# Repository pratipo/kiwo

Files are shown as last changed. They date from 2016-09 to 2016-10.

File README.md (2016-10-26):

# kiwo
post digital knitting, hybrid fabrication, digital crafts, social looming
 
> “El acto de tejer se convierte en una metáfora de la vida diaria, y también en una herramienta para construir espacio, construir grupos y comunidades, actividades e ideales que de otra forma permanecerían escondidos, olvidados o perdidos” 
> In The Loop, Knitting now. Jessica Hemmings (2010)

###Overview
Kiwo is an augmented rag loom, an artifact for hybrid fabric manufacture. It's a digital, interactive loom that can manage complex patterns in a user-friendly way. 

An augmented loom is not an elektroknit machine (a fully automated robot into which you feed a pattern and it takes over both the act of producing and the product), nor a traditional loom that gives no feedback to the user. Kiwo is a prototype designed to preserve all the properties of the craft production activity (inherent to the product and the social, physical and emotional activity itself) while speeding up the ability to learn new stitches and transform the number of patterns created or shared into tangible fabrics.

Using a series of simple sensors and actuators Kiwo is able to read the user's work and guide how fabrics are made out of different stitches. Multi-coloured patterns can be made too, by using several strands of colour to produce pictures, motifs and symbols. These complex patterns can be computer generated and easily transferred to the artefact (previously or) after they have been (self)made or distributed.  

A mobile app allows users to transfer these patterns into Kiwo, while enjoying outdoor and social life.

###Tech

A MEAN2 stack ecosystem plus an electronic device thaqt receives knitting-pattern data through BLE
 * Mongo schema wip
 * Ionic2 port wip
 * Nodejs wip
 
 * Pcb and bom wip (ws2812 + ble + 328)
 * Loom body and needle wip
 * Stitch detection wip
  
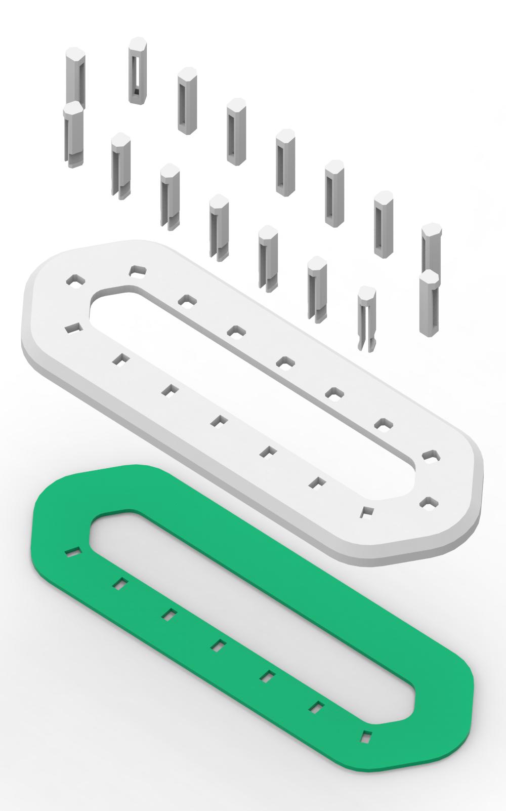
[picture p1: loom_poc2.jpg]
second poc. with needle A vs needle B

second poc. needle A vs needle B

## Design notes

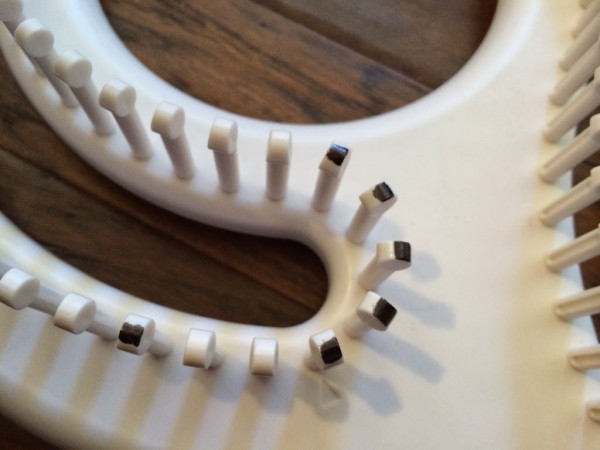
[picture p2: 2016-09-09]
proposal/marker patterns on loom.jpg

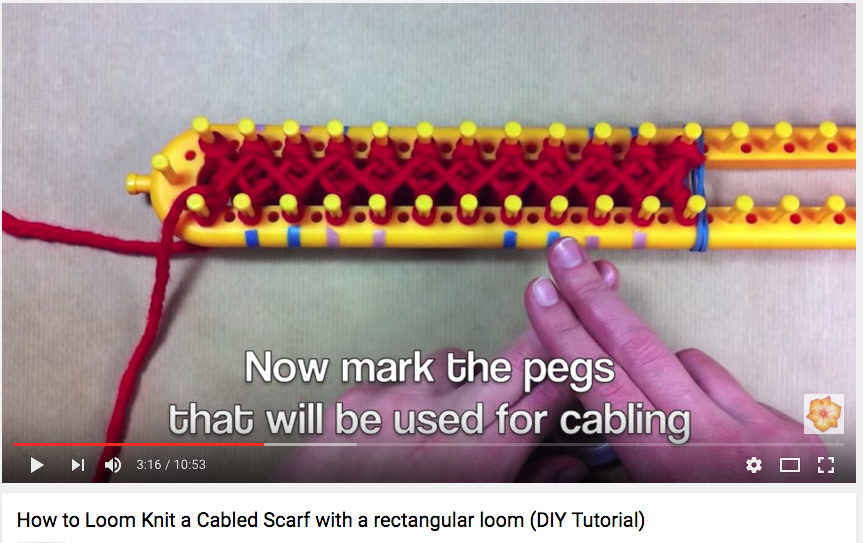
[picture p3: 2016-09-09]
proposal/color tape patterns on loom.png

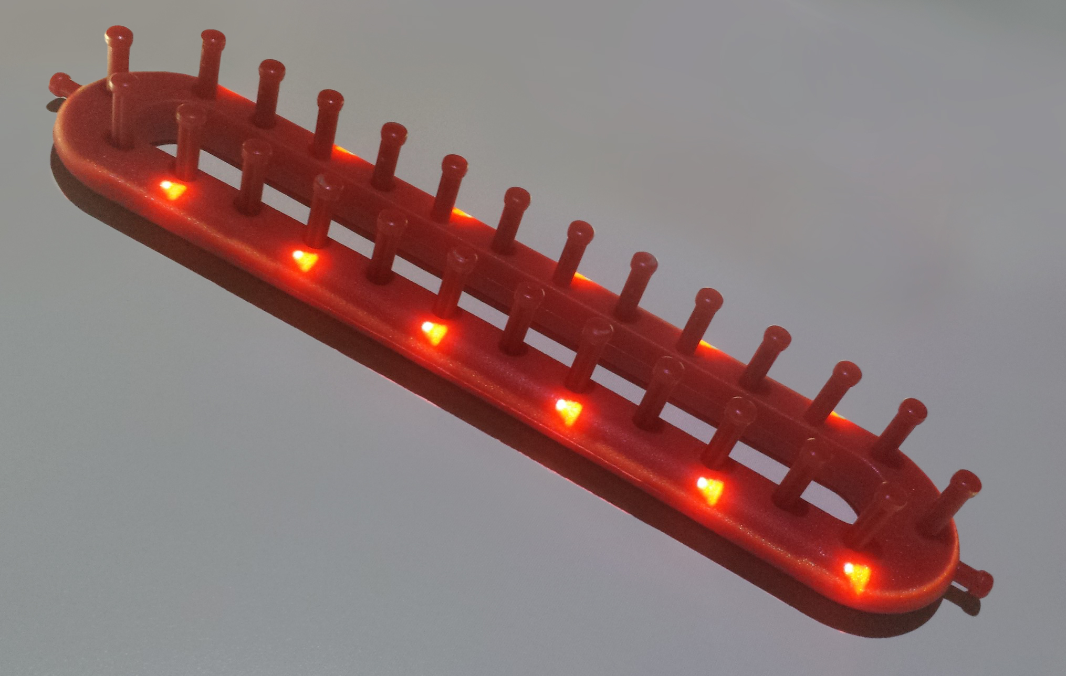
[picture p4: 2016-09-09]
proposal/kiwo_mockup.jpg

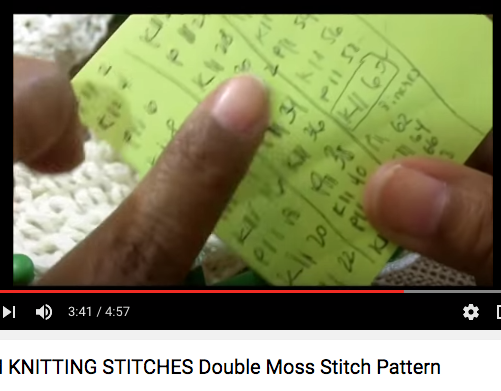
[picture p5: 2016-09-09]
proposal/paper patterns.png

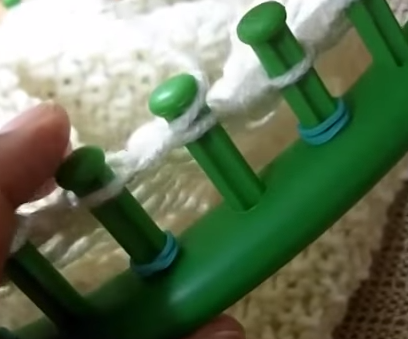
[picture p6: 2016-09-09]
proposal/rubberband patterns on loom.png

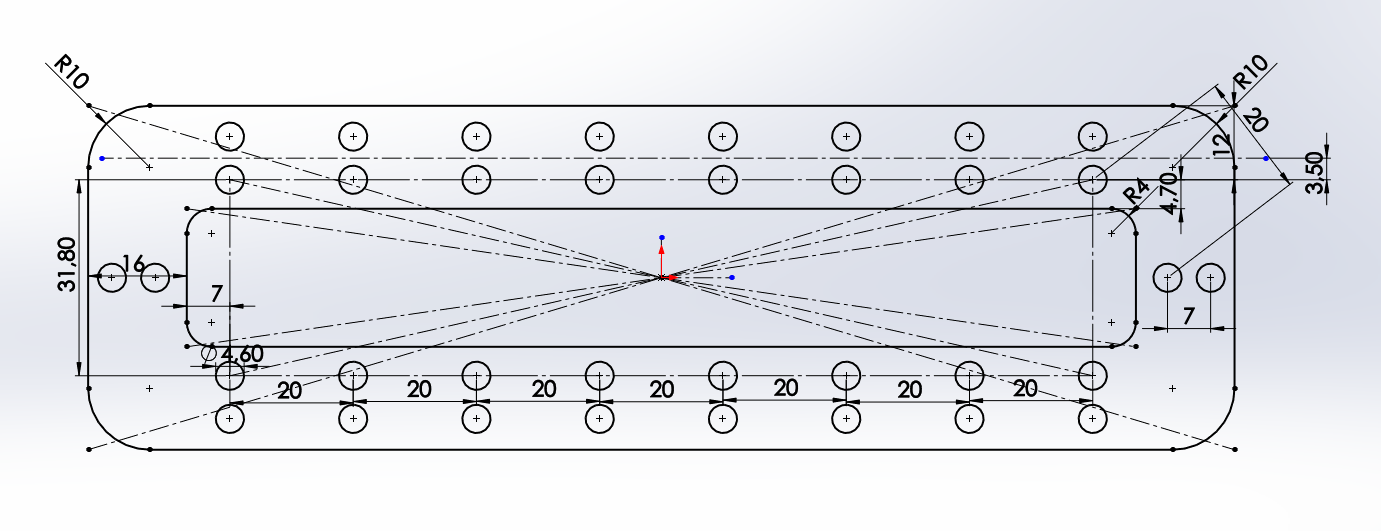
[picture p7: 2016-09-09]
kiwo_loom_poc1/loom_poc1.png

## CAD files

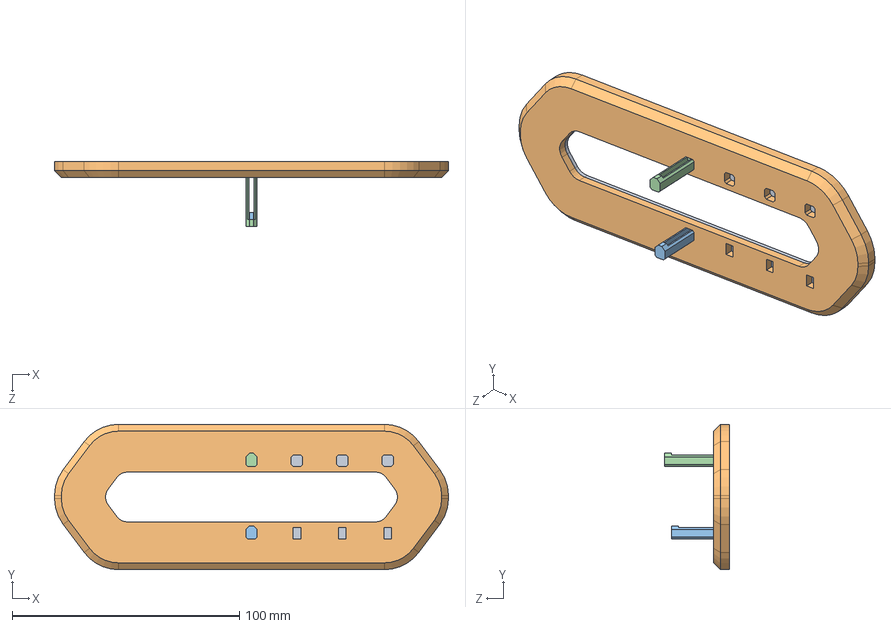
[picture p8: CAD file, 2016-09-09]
kiwo_loom_poc2/kiwo_poc2.SLDASM
173.5 x 64.0 x 28.6 mm
pcb^kiwo_poc2
case^kiwo_poc2
peg^kiwo_poc2
peg2^kiwo_poc2

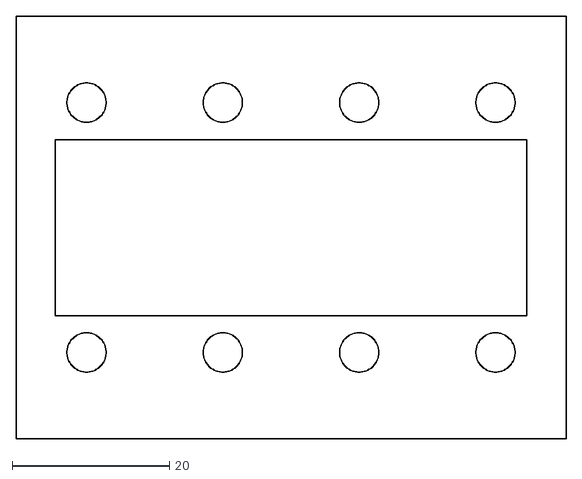
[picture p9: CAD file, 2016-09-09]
kicad/kiwo_poc1/kiwo_poc1.dxf
70.0 x 53.8

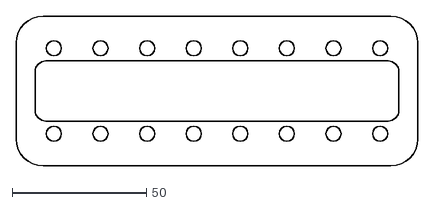
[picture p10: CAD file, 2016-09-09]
kicad/kiwo_poc2/kiwo_poc2_.dxf
149.5 x 55.8

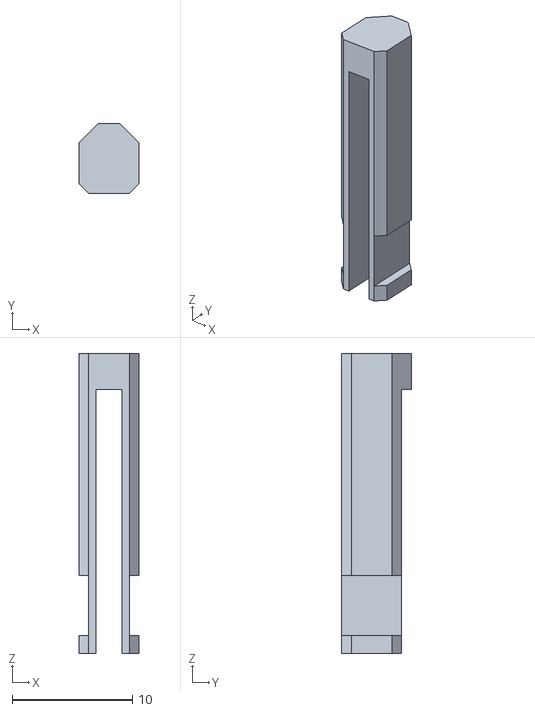
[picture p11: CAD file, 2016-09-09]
kiwo_loom_poc2/kiwo_peg0.STL
5.00 x 5.80 x 25.0

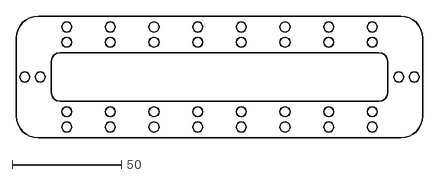
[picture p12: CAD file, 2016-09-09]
kiwo_poc0/kiwo.DXF
186.0 x 55.8

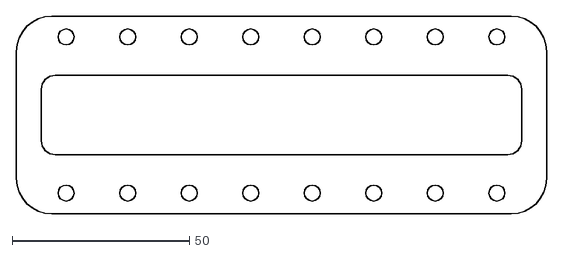
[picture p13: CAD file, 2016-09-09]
kicad/kiwo_poc2/kiwo_poc2_analogtest.dxf
149.5 x 55.8

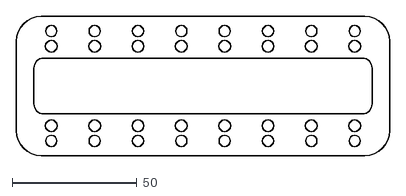
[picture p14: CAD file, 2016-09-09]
kicad/kiwo_poc2/kiwo_poc2_wood.dxf
149.5 x 55.8

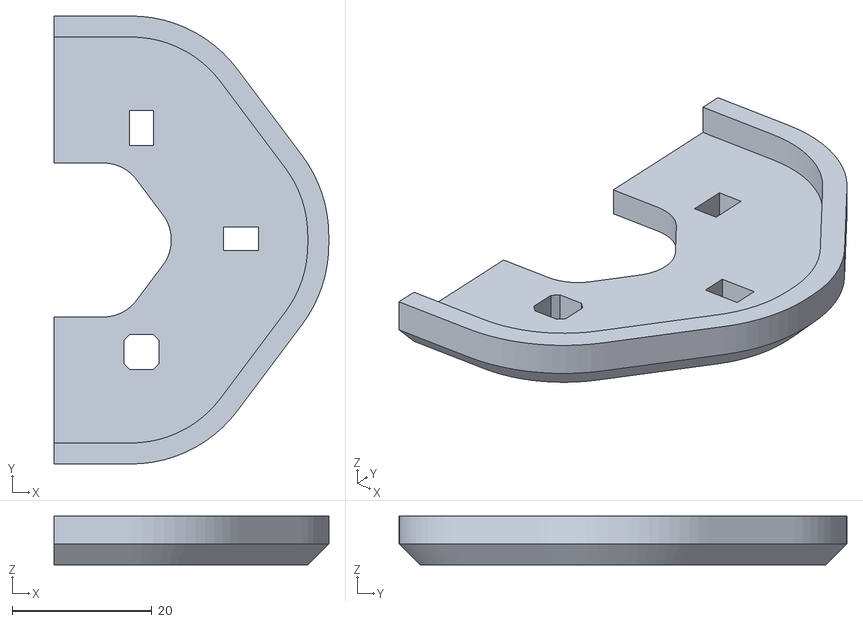
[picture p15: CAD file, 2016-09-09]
kiwo_loom_poc2/kiwo_case.STL
39.2 x 64.0 x 7.00

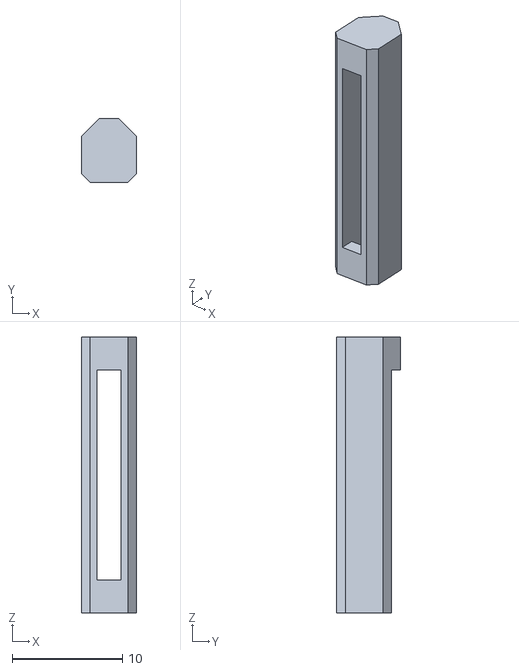
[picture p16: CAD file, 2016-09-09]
kiwo_loom_poc2/kiwo_peg1.STL
5.00 x 5.80 x 25.0

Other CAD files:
kiwo_loom_poc1/kiwo_poc1_cut_shape.SLDPRT
kicad/kiwo_poc1/kiwo_poc1_.DXF
kiwo_loom_poc2/kiwo_poc2.sldprt

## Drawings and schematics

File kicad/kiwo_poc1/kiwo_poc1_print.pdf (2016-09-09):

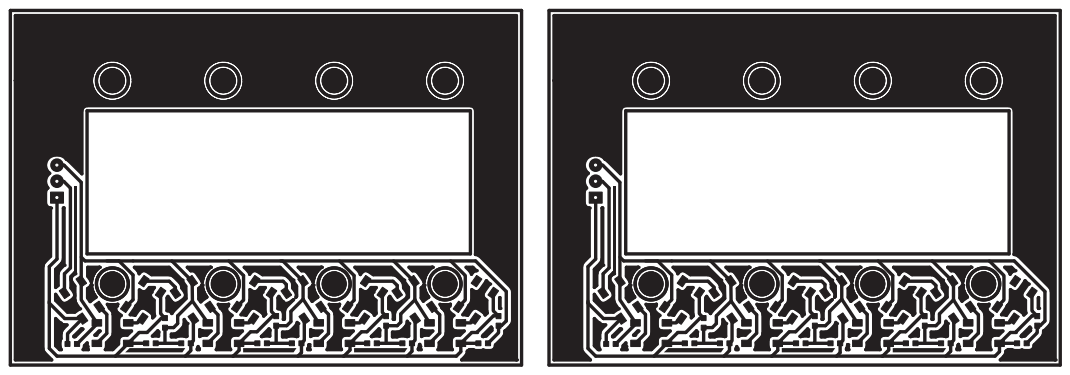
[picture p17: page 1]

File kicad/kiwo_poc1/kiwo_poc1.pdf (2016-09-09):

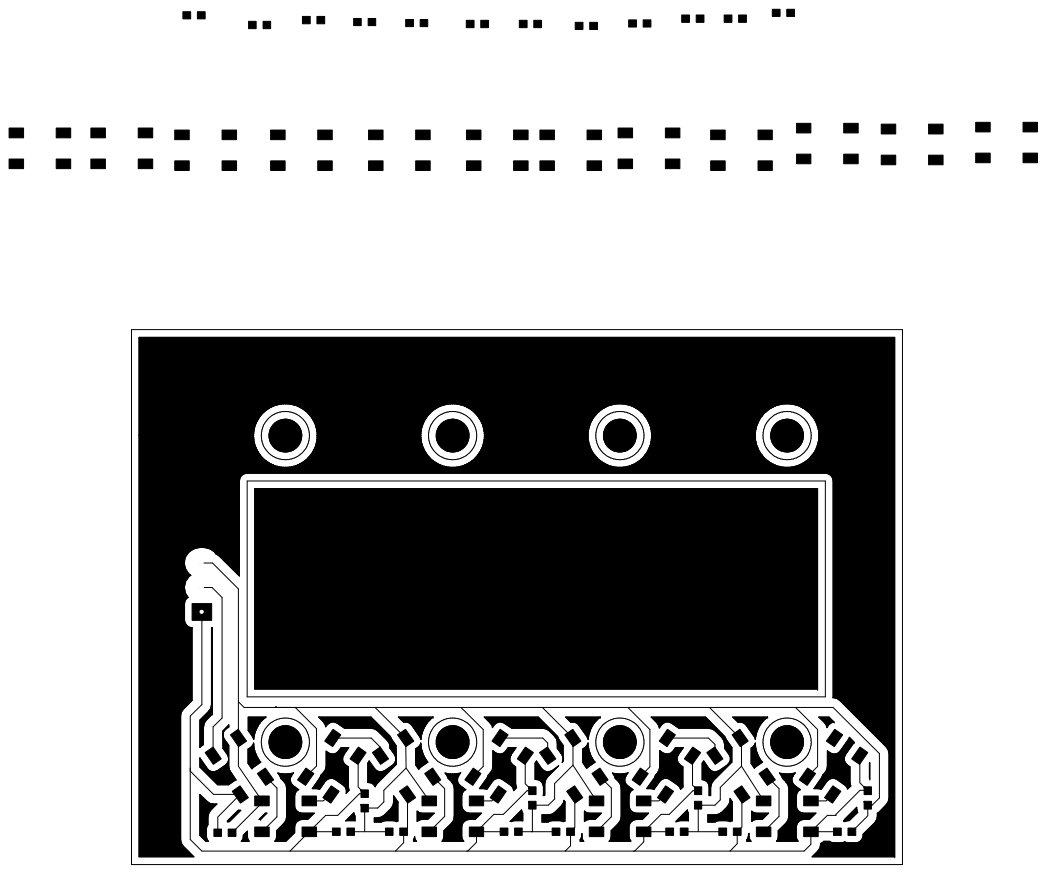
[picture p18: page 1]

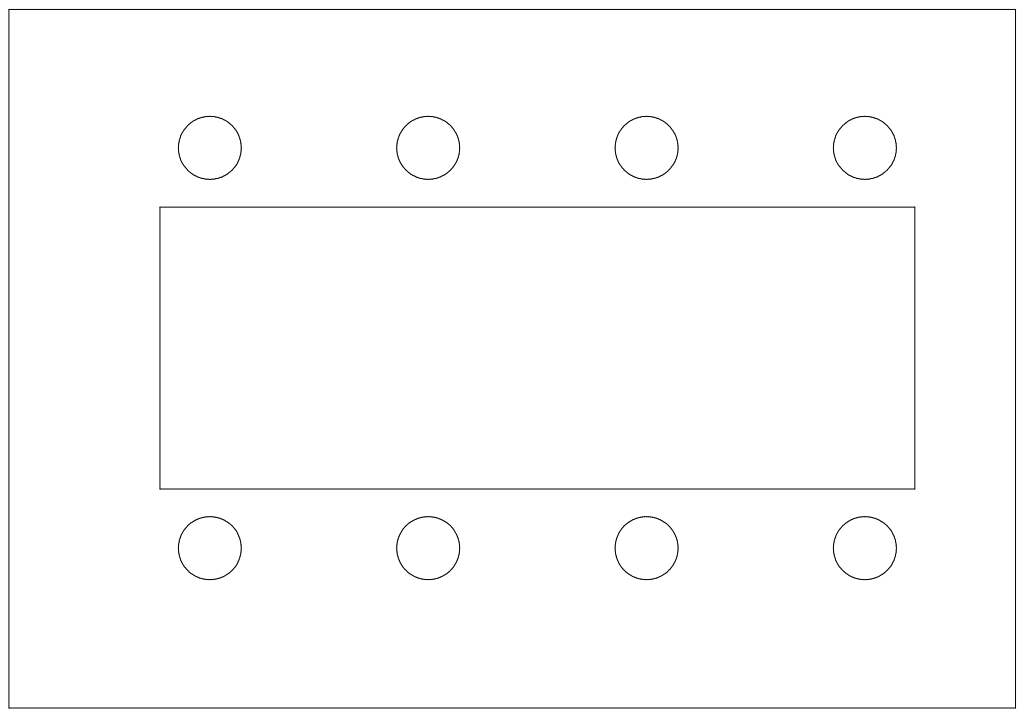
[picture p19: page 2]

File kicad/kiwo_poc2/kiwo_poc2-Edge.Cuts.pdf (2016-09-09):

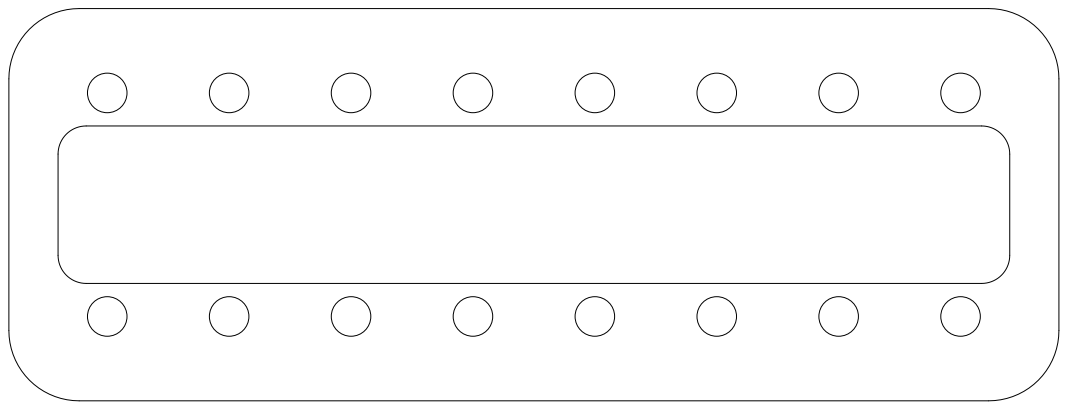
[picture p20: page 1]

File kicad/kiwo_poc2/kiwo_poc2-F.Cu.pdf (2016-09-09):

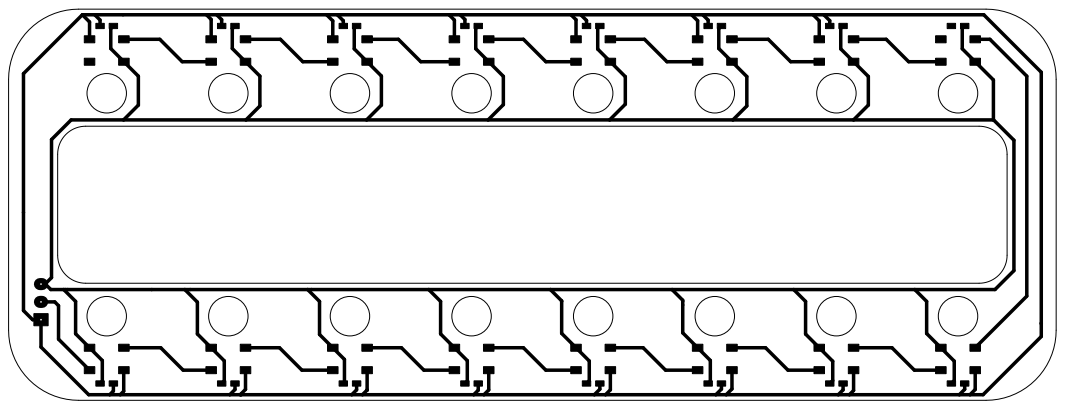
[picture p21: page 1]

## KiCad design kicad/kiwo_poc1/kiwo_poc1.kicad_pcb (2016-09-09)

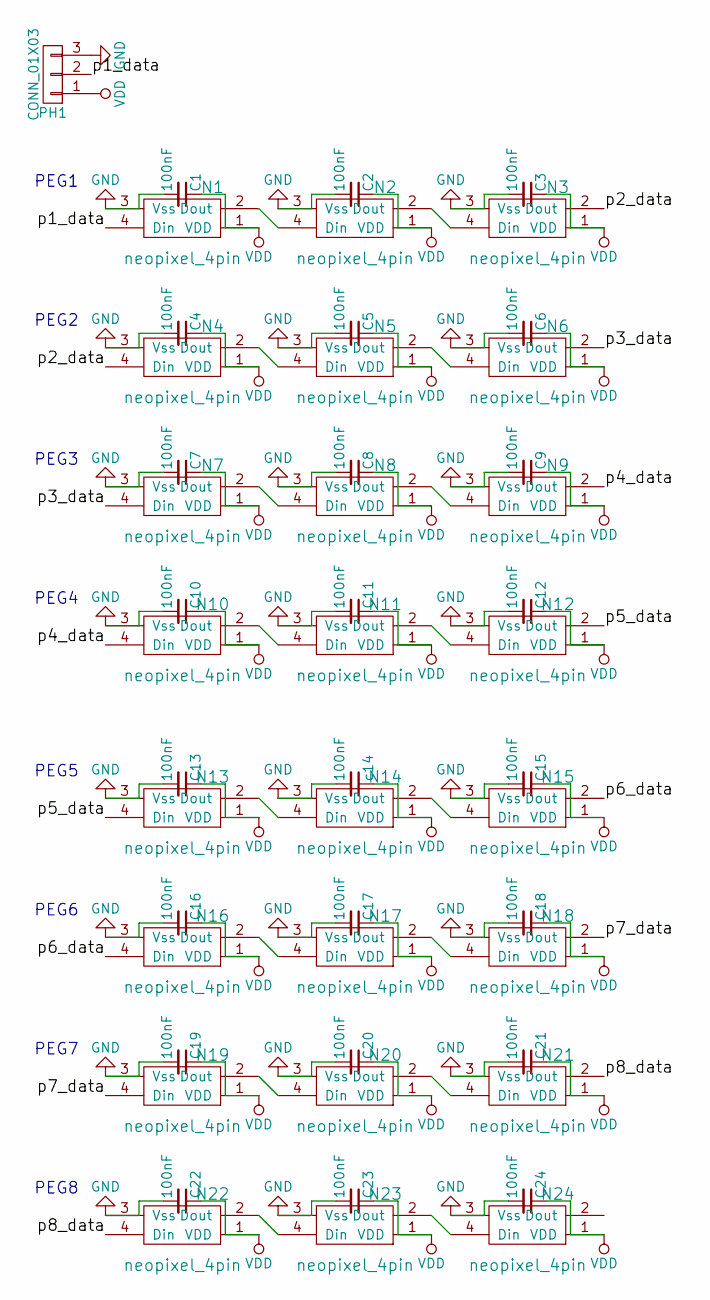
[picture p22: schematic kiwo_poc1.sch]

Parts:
C1, C2, C3, C4, C5, C6, C7, C8, C9, C10, C11, C12, C13, C15, C16, C17, C18, C19, C20, C21, C22, C23, C24: 100nF; C_0603
N1, N2, N3, N4, N5, N6, N7, N8, N9, N10, N11, N12, N13, N14, N15, N16, N17, N18, N19, N20, N21, N22, N23, N24: neopixel_4pin; neopixel_4pins
PH1: CONN_01X03; Pin_Header_Angled_1x03
c14: 100nF; C_0603

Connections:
/p1_data: N1.4 (Din), PH1.2
/p2_data: N3.2 (Dout), N4.4 (Din)
/p3_data: N6.2 (Dout), N7.4 (Din)
/p4_data: N9.2 (Dout), N10.4 (Din)
/p5_data: N12.2 (Dout), N13.4 (Din)
/p6_data: N15.2 (Dout), N16.4 (Din)
/p7_data: N18.2 (Dout), N19.4 (Din)
/p8_data: N21.2 (Dout), N22.4 (Din)
GND: C1.2, C2.2, C3.2, C4.2, C5.2, C6.2, C7.2, C8.2, C9.2, C10.2, C11.2, C12.2, C13.2, C15.2, C16.2, C17.2, C18.2, C19.2, C20.2, C21.2, C22.2, C23.2, C24.2, N1.3 (Vss), N2.3 (Vss), N3.3 (Vss), N4.3 (Vss), N5.3 (Vss), N6.3 (Vss), N7.3 (Vss), N8.3 (Vss), N9.3 (Vss), N10.3 (Vss), N11.3 (Vss), N12.3 (Vss), N13.3 (Vss), N14.3 (Vss), N15.3 (Vss), N16.3 (Vss), N17.3 (Vss), N18.3 (Vss), N19.3 (Vss), N20.3 (Vss), N21.3 (Vss), N22.3 (Vss), N23.3 (Vss), N24.3 (Vss), PH1.3, c14.2
unnamed: N1.2 (Dout), N2.4 (Din)
unnamed: N2.2 (Dout), N3.4 (Din)
unnamed: N4.2 (Dout), N5.4 (Din)
unnamed: N5.2 (Dout), N6.4 (Din)
unnamed: N7.2 (Dout), N8.4 (Din)
unnamed: N8.2 (Dout), N9.4 (Din)
unnamed: N10.2 (Dout), N11.4 (Din)
unnamed: N11.2 (Dout), N12.4 (Din)
unnamed: N13.2 (Dout), N14.4 (Din)
unnamed: N14.2 (Dout), N15.4 (Din)
unnamed: N16.2 (Dout), N17.4 (Din)
unnamed: N17.2 (Dout), N18.4 (Din)
unnamed: N19.2 (Dout), N20.4 (Din)
unnamed: N20.2 (Dout), N21.4 (Din)
unnamed: N22.2 (Dout), N23.4 (Din)
unnamed: N23.2 (Dout), N24.4 (Din)
VDD: C1.1, C2.1, C3.1, C4.1, C5.1, C6.1, C7.1, C8.1, C9.1, C10.1, C11.1, C12.1, C13.1, C15.1, C16.1, C17.1, C18.1, C19.1, C20.1, C21.1, C22.1, C23.1, C24.1, N1.1 (VDD), N2.1 (VDD), N3.1 (VDD), N4.1 (VDD), N5.1 (VDD), N6.1 (VDD), N7.1 (VDD), N8.1 (VDD), N9.1 (VDD), N10.1 (VDD), N11.1 (VDD), N12.1 (VDD), N13.1 (VDD), N14.1 (VDD), N15.1 (VDD), N16.1 (VDD), N17.1 (VDD), N18.1 (VDD), N19.1 (VDD), N20.1 (VDD), N21.1 (VDD), N22.1 (VDD), N23.1 (VDD), N24.1 (VDD), PH1.1, c14.1

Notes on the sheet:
PEG1
PEG2
PEG3
PEG4
PEG5
PEG6
PEG7
PEG8

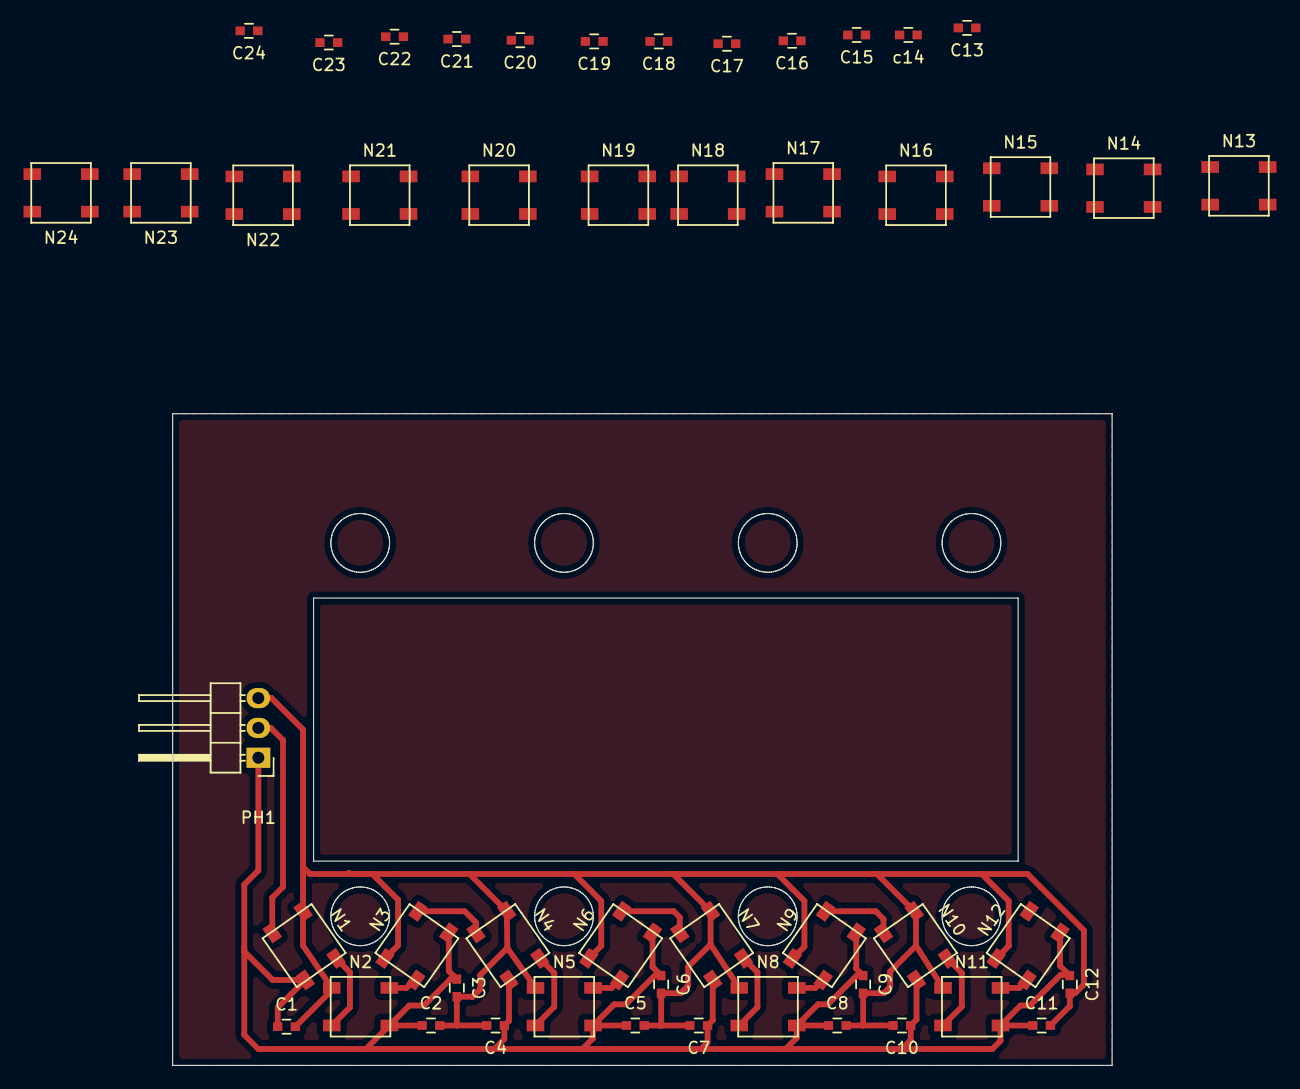
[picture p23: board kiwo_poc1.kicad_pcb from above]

Board: 2 copper layers, 80.0 x 55.5 mm, 49 parts (0 on the bottom side), 26 nets.

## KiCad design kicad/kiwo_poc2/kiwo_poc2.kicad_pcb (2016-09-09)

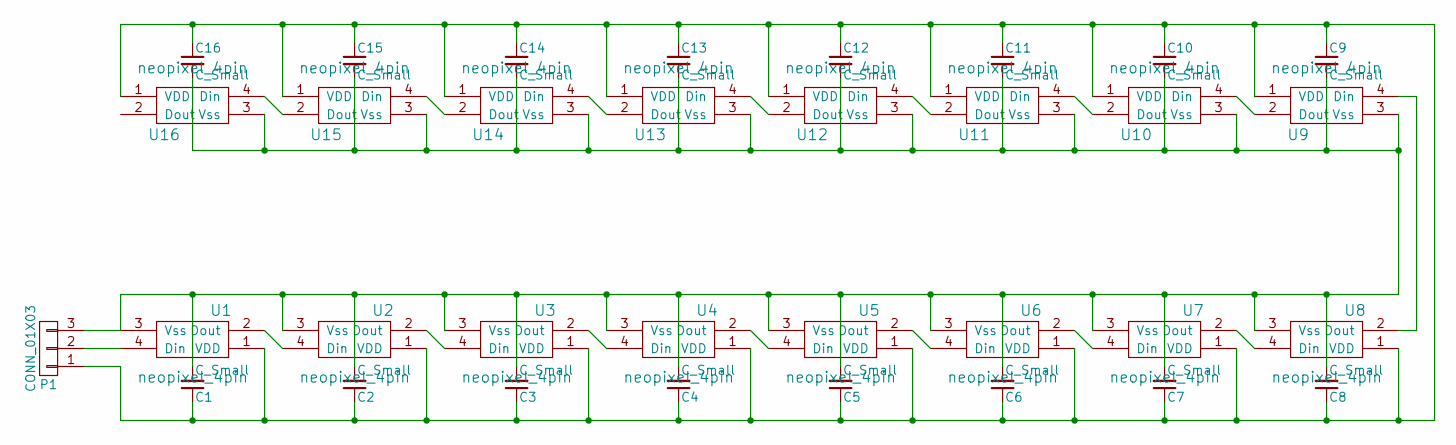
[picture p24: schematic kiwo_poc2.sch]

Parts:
C1, C2, C3, C4, C5, C6, C7, C8, C9, C10, C11, C12, C13, C14, C15, C16: C_Small; C_0603_HandSoldering
P1: CONN_01X03; Pin_Header_Angled_1x03
U1, U2, U3, U4, U5, U6, U7, U8, U9, U10, U11, U12, U13, U14, U15, U16: neopixel_4pin; neopixel_4pins

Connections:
unnamed: C1.1, C2.1, C3.1, C4.1, C5.1, C6.1, C7.1, C8.1, C9.1, C10.1, C11.1, C12.1, C13.1, C14.1, C15.1, C16.1, P1.1, U1.1 (VDD), U2.1 (VDD), U3.1 (VDD), U4.1 (VDD), U5.1 (VDD), U6.1 (VDD), U7.1 (VDD), U8.1 (VDD), U9.1 (VDD), U10.1 (VDD), U11.1 (VDD), U12.1 (VDD), U13.1 (VDD), U14.1 (VDD), U15.1 (VDD), U16.1 (VDD)
unnamed: C1.2, C2.2, C3.2, C4.2, C5.2, C6.2, C7.2, C8.2, C9.2, C10.2, C11.2, C12.2, C13.2, C14.2, C15.2, C16.2, P1.3, U1.3 (Vss), U2.3 (Vss), U3.3 (Vss), U4.3 (Vss), U5.3 (Vss), U6.3 (Vss), U7.3 (Vss), U8.3 (Vss), U9.3 (Vss), U10.3 (Vss), U11.3 (Vss), U12.3 (Vss), U13.3 (Vss), U14.3 (Vss), U15.3 (Vss), U16.3 (Vss)
unnamed: P1.2, U1.4 (Din)
unnamed: U1.2 (Dout), U2.4 (Din)
unnamed: U2.2 (Dout), U3.4 (Din)
unnamed: U3.2 (Dout), U4.4 (Din)
unnamed: U4.2 (Dout), U5.4 (Din)
unnamed: U5.2 (Dout), U6.4 (Din)
unnamed: U6.2 (Dout), U7.4 (Din)
unnamed: U7.2 (Dout), U8.4 (Din)
unnamed: U8.2 (Dout), U9.4 (Din)
unnamed: U10.2 (Dout), U11.4 (Din)
unnamed: U9.2 (Dout), U10.4 (Din)
unnamed: U11.2 (Dout), U12.4 (Din)
unnamed: U12.2 (Dout), U13.4 (Din)
unnamed: U13.2 (Dout), U14.4 (Din)
unnamed: U14.2 (Dout), U15.4 (Din)
unnamed: U15.2 (Dout), U16.4 (Din)

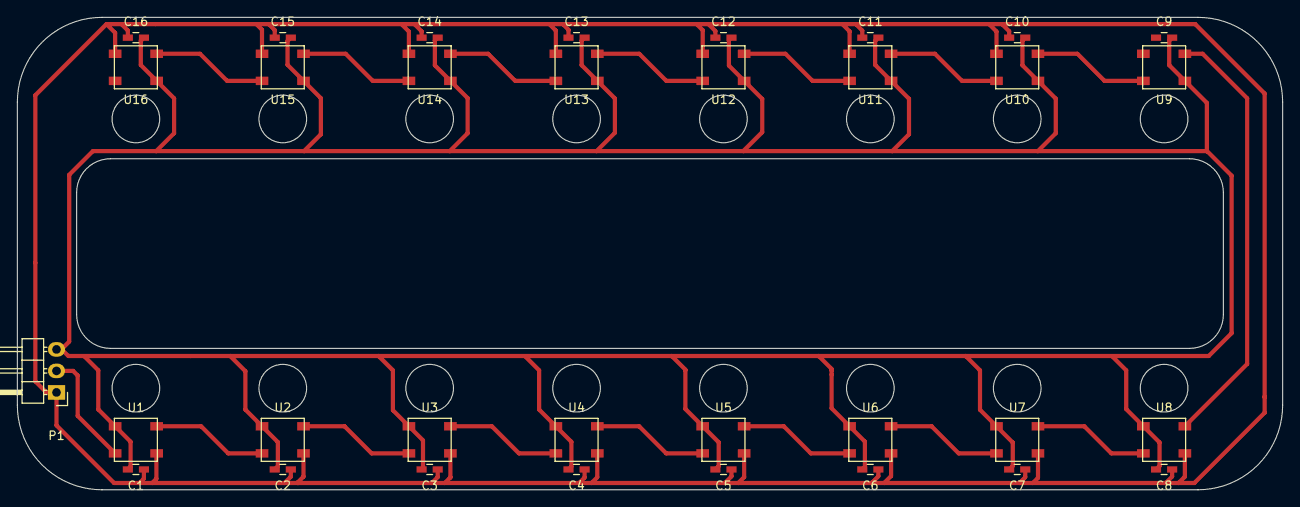
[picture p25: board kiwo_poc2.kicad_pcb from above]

Board: 2 copper layers, 149.4 x 55.8 mm, 33 parts (0 on the bottom side), 18 nets.

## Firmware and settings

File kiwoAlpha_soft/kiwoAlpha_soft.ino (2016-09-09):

#include "JsonStreamingParser.h"
//#include "JsonListener.h"
#include "kiwoParser.h"
//#include "nutsnbolts.h"

#include <Adafruit_NeoPixel.h>
#include <SoftwareSerial.h>   //Software Serial Port

//-------------------
#define RxD 2
#define TxD 3
//-------------------
#define NEOPIN 6
#define PEGS 26
//-------------------

SoftwareSerial BLE(RxD, TxD);

JsonStreamingParser parser;
kiwoParser kparser;

Adafruit_NeoPixel strip = Adafruit_NeoPixel(PEGS , NEOPIN, NEO_GRB + NEO_KHZ800);

const byte interruptPinF = 2;
const byte interruptPinB = 2;

volatile byte buttonPressed = LOW;
volatile int step = 0;

int eepromPos = 0;

// json: {id:|0-65536|, type:|"single"|"round"|"double"|, colors:[B, B, B, ...] size:{width:W, length:L}, pattern:[I, I , I ....]} ; 
  // I  [a b c d e f g h   i j k l m n o p]: int | 16 bits
    // [a b] color: 2 bits 
    // [c d e f g h i j]peg number: byte
    // [k l m] stitch type: 3 bits (cast-on, cast off, e-wrap , u-wrap, purl, cable, increase, decrease )
    // [n o p] extra: 3 bits (cable: target offset (from origin): [-4, +4])

struct dataStruct{
  int id;
  uint8_t type;
  uint8_t sizeW;
  uint8_t sizeL;
  uint8_t peg;
  int stitch[255];
}pattern;

//int lapse = 150; // ?

void setup() {
  // init parser
  parser.setListener(&kparser);

  // init button pin & interrupt
  pinMode(interruptPinF, INPUT_PULLUP);
  attachInterrupt(digitalPinToInterrupt(interruptPinF), fBoton, RISING); // detect button release
  pinMode(interruptPinB, INPUT_PULLUP);
  attachInterrupt(digitalPinToInterrupt(interruptPinB), bBoton, RISING); // detect button release

  // init neopixel
  strip.begin();

  rainbow(5, PEGS);
  colorStrip(strip.Color(0,0,0), 1);

  // init softserial: HM-10 BLE connection
  pinMode(RxD, INPUT);
  pinMode(TxD, OUTPUT);
  setupBleConnection();
  
  // init serial debugging
  Serial.begin(9600);
  Serial.println("KNIT IT WITH OTHERS alpha");
}

void loop() {

  char recvChar;
  int jsonSize = 100;

//  //  receive pattern, parse json file
//  if (BLE.available() > 0) { 
//    char json[100] = {};
//    int i = 0;
//    while (BLE.available()) {
//      recvChar = BLE.read();
//      //Serial.print(recvChar);
//      json[i++] = recvChar;
//    }

    //char json[] = "{\"a\":3, \"b\":{\"c\":\"d\"}}";
    char json[] = "{\"id\":777, \"type\":0, \"colors\":[16711680, 0],  \"size\":{\"width\":8, \"length\":4}, \"pattern\":[16, 80, 144, 208, 272, 336, 400, 464, 16, 80, 144, 208, 272]}";

    
    // results[index] = '\0';
    for (int i = 0; i < sizeof(json); i++) {
      parser.parse(json[i]);
    }
    
    for (int i = 0; i < sizeof(json); i++) {
      //EEPROM.update(address, val); //WRITE
      //address == EEPROM.length() // check position
    }
    
//  }

  if (buttonPressed) {
    if (step >= PEGS) {
      Serial.println("end of pattern");
      colorStrip(strip.Color(255, 0, 0), 3000);
      step = 0;
    }
    else if (step < 0) { // avoid underflowing
      step = 0;
    }

    //stepPattern(step, pattern);

    buttonPressed = LOW;
  }
}

void fBoton() {
  Serial.println("next");
  buttonPressed = HIGH;
  step++;
}

void bBoton() {
  Serial.println("prev");
  buttonPressed = HIGH;
  step--;
}

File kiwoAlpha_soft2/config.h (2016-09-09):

#pragma once

#include <Adafruit_NeoPixel.h>
#include <SoftwareSerial.h>   //Software Serial Port
#include <EEPROM.h>

//-------------------
#define RxD 4
#define TxD 5
//-------------------
#define NEOPIN 6
#define PEGS 26
//-------------------

SoftwareSerial BLE(RxD, TxD);
Adafruit_NeoPixel strip = Adafruit_NeoPixel(PEGS , NEOPIN, NEO_GRB + NEO_KHZ800);

const byte interruptPinF = 2;
const byte interruptPinB = 3;

volatile byte buttonPressed = LOW;
volatile int step = 0;

/*
position: 0 hB
          1 lB

id        2 hB
          3 lB

type      4 B

colors    5  B: R  first  YARN 1
          6  B: G
          7  B: B
          
          8  B: R  second
          9  B: G
          10 B: B
          
          11 B: R  third
          12 B: G
          13 B: B
          
          14 B: R  fourth
          15 B: G
          16 B: B

          17 B: R  first   YARN 2
          18 B: G
          19 B: B
          
          20 B: R  second
          21 B: G
          22 B: B
          
          23 B: R  third
          24 B: G
          25 B: B
          
          26 B: R  fourth
          27 B: G
          28 B: B

          ...              YARN 3
          ...              YARN 4

sizeW     29
sizeL     30

stitches  31 hB: stitch 0
          32 lB
          33 hB: stitch 1
          34 lB
          .....

          /hB/  a b c d e f g h  /lB/  i j k l m n o p
          [a b c d e f g h]   peg number: byte (0-255)
          [i j]             yarn selector
          [k l m]           stitch type: 4 bits (cast-on, cast off, e-wrap , u-wrap, purl, cable, increase, decrease, ... )
          [n o p]           extra: 3 bits (cable: target offset (from origin): [-4, +4])

*/

// eeprom offsets
int idEOffset = 2;
int typeEOffset = 4;
int colorsEOffset = 5;
int wEOffset = 29;
int lEOffset = 30;
int stitchEOffset = 31;

// stich bitwise offsets
byte pegOffset =  8;
byte yarnOffset =  6;
byte typeOffset =  3;
byte xOffset =  0;


//byte xtra(word stitch){
//  byte x = (stitch>>xOffset);
//  x = x&B00000111;
//  return x;
//}

byte type(word stitch){
  byte t = (stitch>>typeOffset);
  t = t&B00000111;
  return t;
}

byte yarn(word stitch){
  byte y = (stitch>>yarnOffset);
  y = y&B00000011;
  return y;
}

uint32_t colour(word stitch){
  byte y = yarn(stitch);
  byte t = type(stitch);

  byte r = EEPROM.read(colorsEOffset + y*4*3 + t*3); // get the indexed color
  byte g = EEPROM.read(colorsEOffset + y*4*3 + t*3+1); // get the indexed color
  byte b = EEPROM.read(colorsEOffset + y*4*3 + t*3+2); // get the indexed color

  uint32_t rgb = (uint32_t)r << 16 | (uint32_t)g << 8 | (uint32_t)b;;
  return rgb;
}

byte peg(word stitch){
  byte p = (stitch>>pegOffset);
  p = p&B11111111;
  return p;
}

int patternLength(){
  if (EEPROM.read(idEOffset) || EEPROM.read(idEOffset+1) ) { //pattern loaded ?
    int s = (int) EEPROM.read(wEOffset)*EEPROM.read(lEOffset);
    return s;
  }
  else {
    Serial.println("ERROR! no pattern loaded in eeprom!");
    return -1;
  }
}





    

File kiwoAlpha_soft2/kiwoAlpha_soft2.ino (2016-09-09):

/*
 * KIWO -knit it with others- alpha 2
 * medialab prado, june 2016
 * Copyrights (C) 2016 Raul Nieves Pardo
 * GPL v3  https://www.gnu.org/licenses/gpl-3.0.html
 */

#include <Adafruit_NeoPixel.h>
#include <SoftwareSerial.h>   //Software Serial Port
#include <EEPROM.h>

#include "config.h"
#include "leds.h"
#include "nutsnbolts.h"


//-------------------

void setup() {

  // init button pin & interrupt
  pinMode(interruptPinF, INPUT_PULLUP);
  attachInterrupt(digitalPinToInterrupt(interruptPinF), fBoton, RISING); // detect button release
  pinMode(interruptPinB, INPUT_PULLUP);
  attachInterrupt(digitalPinToInterrupt(interruptPinB), bBoton, RISING); // detect button release

  // init neopixel
  strip.begin();

  // demo lightning
  rainbow(5, PEGS);
  colorStrip(strip.Color(0,0,0), 1);

  // init softserial: HM-10 BLE connection
  pinMode(RxD, INPUT);
  pinMode(TxD, OUTPUT);
  setupBleConnection();
  
  // init serial debugging
  Serial.begin(9600);
  Serial.println("KNIT IT WITH OTHERS alpha \n");

  delay(500);
  
  // recover last position!
  if (EEPROM.read(0) && EEPROM.read(1) ) { 
    step = (int) EEPROM.read(0)<<8 | (int) EEPROM.read(1);
    
    Serial.print("recovering last position = ");
    Serial.println(step);
  }

  buttonPressed = LOW;
}

//-------------------

void loop() {
  
  //  receive pattern, parse json file
  if (BLE.available() > 0) { 
    Serial.println("BLE available");
    //check for a repeated stich pattern inccoming, return

    byte val;
    int address = 2;
    while (BLE.available()) {
      val = BLE.read();
      Serial.println(val);
      
      EEPROM.update(address++, val);
      
      if (address == EEPROM.length()){
        Serial.println("error EEPROM length");
        colorStrip(strip.Color(255,0,0), 2000);
        //return;
      }
    }

    eepromRead();

    // reset "step" pointer
    EEPROM.update(0, B00000000);
    EEPROM.update(1, B00000000);
  }

  if (buttonPressed) {
    Serial.println("button pressed");
    buttonPressed = LOW;
    
    if (step >= patternLength()) {
      Serial.println("end of pattern");
      colorStrip(strip.Color(0, 255, 0), 3000);
      step = 0;
      return;
    }
    else if (step < 0) { // avoid underflowing
      Serial.println("prevented underflow");
      step = 0;
    }

    Serial.println("step it");
    stepPattern(step);

    //update persistent "step" 
    EEPROM.update(0, (byte)((step>>8)&B11111111));
    EEPROM.update(1, (byte)(step&B11111111));
  }
}

void stepPattern(int step){
  int eepromPos = stitchEOffset + step*2;
  byte hB = EEPROM.read(eepromPos);
  byte lB = EEPROM.read(eepromPos+1);

  word stitch = (word)hB<<8 | (word)lB; // built up a word from two bytes

  uint32_t c = colour(stitch);
  byte p = peg(stitch);
  
  stitchStrip(c, p);  
}
